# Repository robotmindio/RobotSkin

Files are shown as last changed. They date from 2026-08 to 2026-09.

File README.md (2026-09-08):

# RobotSkin

<p align="center">
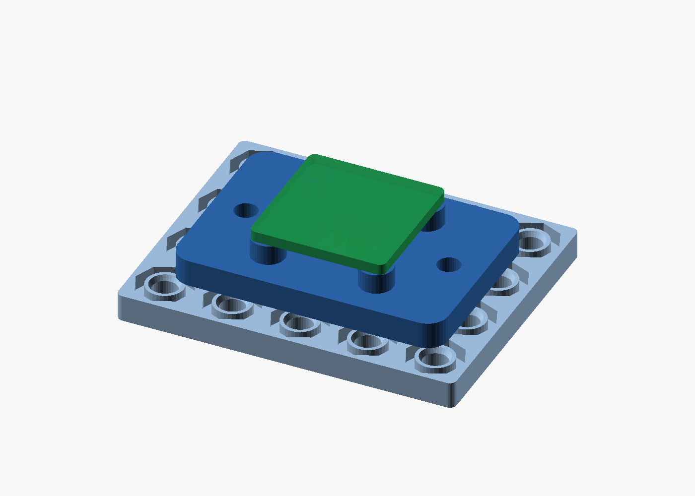
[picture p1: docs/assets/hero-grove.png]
A Grove sensor carrier locked to a RobotSkin plate
  
</p>

**Print a mechanical skin for your electronics.** RobotSkin turns sensors,
microcontrollers, cameras, and mounting surfaces into one reusable building
system. Print a plate, add a carrier or adapter, and lock the result with the
same 10 mm connector grid.

It is an OpenSCAD design library with ready-to-print STL exports—made for FDM
printers, prototypes that change, and projects that should not need a new
custom enclosure every time.

> **V0.1 is engineering hardware.** Print the calibration part before a larger
> build; the interface is reusable, but it is not yet load-rated.

## One interface, many jobs

- **Structural surfaces:** 8×8 plates and smaller full-through mounting plates.
- **Structures:** flat, inner-corner, and outer-corner joins.
- **Electronics:** Seeed Grove 2×2 Gesture, 4×2 IMU 9DOF, and 16×2 LCD
  carriers, a cable clip, a solid UNO-format carrier, and an inverted
  dual-USB-C 44-pin ESP32-S3 carrier with exposed pins.
- **Mounting adapters:** camera-tripod, 20-series extrusion, and TH35 DIN rail
  adapters, plus an H25T servo-horn plate.

<p align="center">
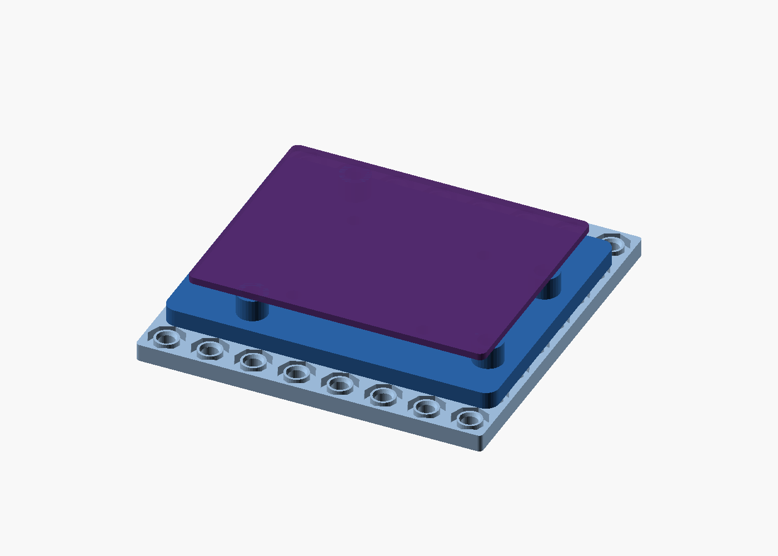
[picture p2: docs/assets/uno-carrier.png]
UNO-format carrier on a RobotSkin plate
  
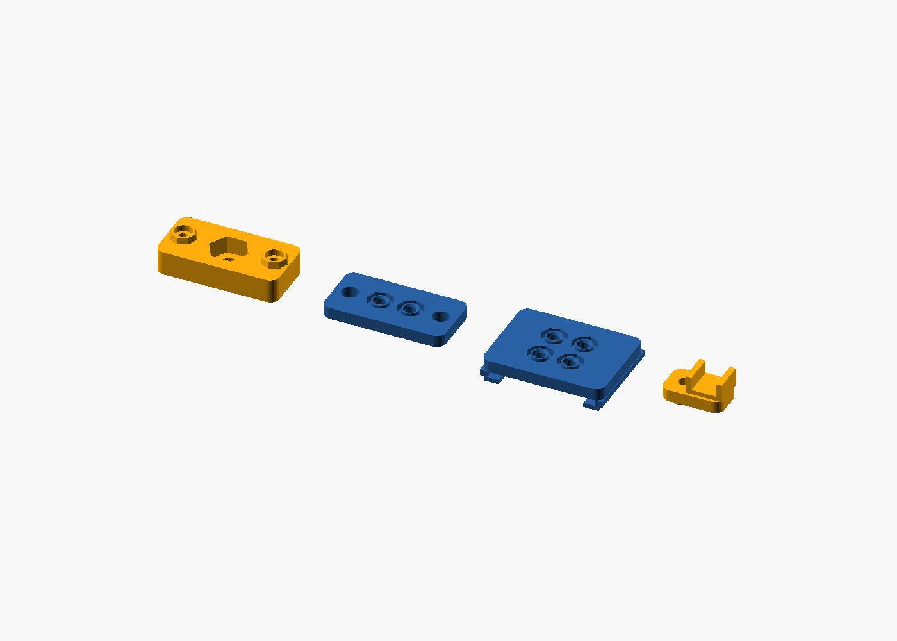
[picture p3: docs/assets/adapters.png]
RobotSkin mounting adapters
  
</p>

Every part shares the same connector: a blind octagonal port accepts a hollow
octagonal peg. Press it together for a temporary fit; for a permanent joint,
install an M3×3×4 heat-set insert in the plate port and fasten it through the
peg centre with an M3×6 pan-head screw.

That means a Grove LCD carrier, a DIN mount, and a tripod adapter all attach to the
same plate without inventing another mechanical standard.

## Start here

1. Print the calibration parts and tune your printer's fit.
2. Print a plate and a join or carrier.
3. Press-fit the peg into the plate port.
4. Add an insert and M3 screw only where you want the joint locked.

The exact calibration method is in [docs/CALIBRATION.md](docs/CALIBRATION.md).
Assembly instructions and the approved hardware are in
[docs/ASSEMBLY.md](docs/ASSEMBLY.md) and [docs/PRODUCT.md](docs/PRODUCT.md).

## Print a part

Download a released STL from `stl/`, or generate the complete set locally:

```bash
./scripts/build.sh
```

Run the fit samples first:

```bash
./scripts/build_test_parts.sh
```

Recommended orientation, materials, and acceptance checks are in
[docs/PRINTING.md](docs/PRINTING.md) and [docs/QUALITY.md](docs/QUALITY.md).

## Design your own part

The reusable public library is [scad/lib/robotskin.scad](scad/lib/robotskin.scad).
For example, define compatible plates by grid count:

```scad
include <scad/lib/robotskin.scad>

plate(8, 8);  // 80 × 80 mm
plate(5, 3);  // 50 × 30 mm
plate(3, 3, thickness=8);  // double-thickness custom plate
```

The public component API and mechanical rules are documented in
[docs/LIBRARY.md](docs/LIBRARY.md) and [docs/INTERFACE.md](docs/INTERFACE.md).
Export entry points live in `scad/parts/`; the build discovers them
automatically.

## Safety and release status

RobotSkin V0.1 is not load-rated or safety-critical hardware. Verify fit,
print quality, and your actual payload before use. The release package can be
regenerated and checked locally with:

```bash
./scripts/package_release.sh
```

This builds all STLs, validates that meshes are closed and connected, renders
previews, and writes a versioned archive plus SHA-256 checksum in `dist/`.

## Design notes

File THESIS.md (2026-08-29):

# RobotSkin thesis

RobotSkin is a modular system for sensors and robotics that children and
professionals can understand and use. It must stay as simple and coherent as
possible while allowing parts to connect by hand and be fixed with screws when
a permanent joint is needed. Water resistance is a later product goal, after
the shared dry mechanical interface passes its release gate.

## Minimum first part set

1. **8×8 plate** — the sole single-sided structural surface and mounting grid;
   two identical plates may be fastened back-to-back when both faces are needed.
2. **Flat join** — joins two plates edge-to-edge.
3. **90° join** — joins two plates at a right angle; an explicitly approved
   exterior variant uses the same port and peg interface.
4. **Grove sensor plaque** — mounts a Grove sensor on a plate.

Every future part must reuse this interface. Do not add a new connector,
carrier family, plate size, or enclosure until this four-part set has been
printed and validated.

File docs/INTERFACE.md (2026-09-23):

# RobotSkin interface

The production base plate is `plate(8,8)`: 80×80×4 mm with a full 8×8,
10 mm-pitch port grid. The library derives other plate dimensions from the
same grid standard. Every plate back is flat for reliable printing and surface
mounting.

| Feature | Dimension |
|---|---:|
| Annular octagonal port, across flats | 8.0 mm |
| Octagonal depth | 2.2 mm |
| Insert entry / pilot / insert | 4.6 mm × 0.8 mm / 3.7 mm × 3.0 mm / 4.0 mm OD M3×3×4 |
| Centre boss / peg clearance | 5.6 mm diameter / 5.9 mm diameter |
| Port backing wall | 1.0 mm |
| Corner mounting ports | Standard port plus 3.4 mm M3 clearance through backing wall |
| Through-plate ports | Standard port plus 3.4 mm M3 clearance through every backing wall |
| Peg root / tip | 8.3 / 7.7 mm across flats |
| Peg depth | 2.2 mm |
| Permanent lock | M3×6 pan-head screw, 2 mm insert engagement |
| Grove carrier retention | M2×6 / 1.7 mm pilot (2×2, 4×2); M2.5×6 / 2.1 mm pilot (LCD) |
| Profile 2020 mounting | Two M5 clearance holes, 30 mm apart |
| DIN rail | EN 60715 TH35 rigid end-slide channel |
| Tripod | Captive 1/4-20 hex nut, 4.5 mm maximum screw entry |
| UNO carrier | 68.58×53.34 mm outline, official asymmetric four-hole layout |
| ESP32-S3 dual-USB-C carrier | Header bodies: 22 mm inside, 28 mm outside, 2 mm high; pins outward; PCB body nominal 57×28 mm |

The circular central boss carries the insert for its full 3 mm depth. A visible 4.6 mm,
0.8 mm-deep entry cup leads into the 3.7 mm pilot, so the brass can start
straight from the exposed plate face before heat presses it into the interference fit. The peg
clears the boss, then its centre accepts an M3 screw. Its thinnest wall is 0.7 mm at the calibrated fit;
a four-peg field locates each join face and stops rotation. Every peg has an
identical through-hole and can accept a screw; four screws per tile are the
minimum recommended lock and all eight can be used for maximum strength.

Flat joins mount on the plate face across an edge seam. Angle joins mount in
the inside corner: one leg on the floor face and one on the wall face. Their
plate-contact faces are flat. Water resistance is outside the first release
until a sealed joint has been designed and tested.
Every join is one 20 mm tile spanning two adjacent port columns. A flat tile
has a 2×2 peg field on each plate. The inside angle is one continuous,
geometrically symmetric L-shaped part with the same 5/15 mm connector rows on
each face. Correctly seated plates touch along the full corner line; connector
fit must not be compensated by shifting either plate. Its outer ends use the
same rounded corners as the Grove carrier while both contact faces remain flat.
One to four tiles span a 20–80 mm run on a single surface.

`outer_angle_join` mounts below the floor and outside the wall. Its pegs use
the same port dimensions and sit 9 and 19 mm from the exterior corner.
Like the other joins, every peg has an identical screw-clearance hole.

The four corner stations remain standard connector ports. Their 3.7 mm insert
pilots end at the normal shoulder, while a 3.4 mm M3 clearance continues
through the final 1 mm backing wall. Each corner therefore accepts the normal
peg and heat-set insert or an M3 pan-head mounting screw through the plate.

One plate is the default product. `double_sided_plate(columns,rows)` provides
blind female ports on both faces, including the 40×10 mm 4×1 production row.
It is 8 mm thick so the opposing 3 mm insert pockets retain a 2 mm shared
backing wall. The two sides remain independent: do not drill its ports through.

`through_plate(columns,rows)` is the mounting-oriented variant: every grid
station remains a standard RobotSkin port while its M3 centre continues through
the full plate. The production exports are 5×3 (50×30 mm), 5×8 (50×80 mm),
8×8 (80×80 mm), and 12×10 (120×100 mm).

The Grove carriers have fixed, published PCB footprints: `grove_carrier_2x2()`
fits only the 20×20 mm Seeed Studio 101020083 Grove Gesture v1.0 with two
2.2 mm holes on its centre line; `grove_carrier_4x2()` fits only the 40×20 mm
Seeed Studio 101020585 Grove IMU 9DOF with its asymmetric three 2.2 mm holes.
The LCD carrier fits only Seeed Studio 104020111: its two RobotSkin lock
stations remain outside the 80×40 mm PCB footprint, while four bosses match
its 76×36 mm hole pitch. All Grove PCB pilots are blind and leave 2 mm of
plastic below the screw path.

`ld06_pj030_clamp_base()` and `ld06_pj030_clamp_bar()` retain the holeless
40×20×1.6 mm LD06 PJ030 controller. Two 40 mm bases mount facing inward on
plate rows 30 mm apart and use four total RobotSkin locks. Two bars use four
M3×6 screws and dedicated M3 inserts to clamp the long PCB edges with 0.1 mm
nominal preload. Both connector ends remain unobstructed.

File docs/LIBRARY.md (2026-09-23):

# RobotSkin OpenSCAD library

Include `scad/lib/robotskin.scad`. Dimensions passed to public part modules are
port counts unless a parameter explicitly says otherwise.

```text
standards
  -> port_cut / peg / heat_set_insert
    -> connector_grid / plate_body / join_panel / join_leg
      -> plate / joins / carriers / mounting adapters
        -> scad/parts entry point -> STL
```

## Finished parts

```scad
plate(columns, rows, thickness=RM_PLATE_T);
through_plate(columns, rows, thickness=RM_PLATE_T);
double_sided_plate(columns, rows, thickness=2*RM_PLATE_T);
h25t_horn_plate_3x3(thickness=2*RM_PLATE_T,
                     hub_radius=RM_STS3215_HUB_RADIUS);
h25t_port_cube_3x3();
flat_join(width_ports=2, depth_ports=2);
angle_join(width_ports=2, depth_ports=2);
outer_angle_join(width_ports=2, depth_ports=2, plate_t=RM_PLATE_T);
grove_carrier_2x2();
grove_carrier_4x2();
ld06_pj030_clamp_base();
ld06_pj030_clamp_bar();
grove_lcd_16x2_carrier();
tripod_adapter();
profile_2020_adapter();
din_rail_adapter();
grove_cable_clip();
uno_carrier();
rpi5_usb_carrier();
rpi5_table();
esp32_s3_devkitc_carrier();
pogo_pin_mount();
```

`plate()` requires integer dimensions of at least 2×2. Width and height are
derived as `count × RM_GRID`; `thickness` defaults to 4 mm and may be increased
for custom structural plates. The four corner ports receive the M3 through bore.
`through_plate()` uses the same dimensions and identical octagonal ports, but
continues the 3.4 mm M3 centre path through the backing wall at every station.
`double_sided_plate()` permits positive integer dimensions, including a 4×1
row, and provides standard blind female ports on both faces. It is 8 mm thick
by default, retaining a 2 mm wall between the opposing insert pockets; its
ports are blind, not M3-through.
Join counts control their connector field without changing the shared port,
peg, hardware, or fit standard.

`h25t_horn_plate_3x3()` is an 8 mm, 30×30 mm STS3215 drive plate. It reserves its
four cardinal stations for the STS3215/LeRobot H25T horn's 4×M3 pattern at
7 mm radius and keeps four corner RobotSkin ports with M3-through paths. The
centre screw and four surrounding horn screws all install from the port face;
the plate does not print a servo spline.

`h25t_port_cube_3x3()` mates to those four corner ports with lower pegs and
provides a 30×30×30 mm hub. Its centre and four top edge-centre stations are
female ports; the corners are 22 mm deep M3 head-access bores. Each vertical face
keeps its lower two centred ports and leaves its upper station flat to prevent
intersection. Four corner screw paths continue through the lower pegs into the
drive-plate inserts.

`grove_carrier_2x2()` fits the Seeed Studio 101020083 Grove Gesture v1.0:
its 20×20 mm PCB and two 2.2 mm holes on the centre line. `grove_carrier_4x2()`
fits the Seeed Studio 101020585 Grove IMU 9DOF (ICM20600 + AK09918): its
40×20 mm PCB and asymmetric three-hole pattern. Both retain their PCB with
top-installed M2 thread-forming screws; they do not imply fit for other Grove
modules with the same nominal outline.
The 4×2 carrier base is 40 mm long, matching the PCB; both RobotSkin locks
sit underneath it at ±15 mm rather than extending the carrier at either end.

`ld06_pj030_clamp_base()` is one of two 40 mm bases for the holeless
40×20×1.6 mm LD06 PJ030 controller. Each base has two RobotSkin locks and two
M3 insert pockets. Mount two copies facing inward on plate rows 30 mm apart.
Fasten two copies of `ld06_pj030_clamp_bar()` with four M3×6 screws to clamp
the PCB edges while leaving its underside and both connector ends open.

`grove_lcd_16x2_carrier()` fits only the Seeed Studio 104020111 Grove 16×2 LCD
(White on Blue): its 80×40 mm PCB and four 2.5 mm mounting holes at a 76×36 mm
pitch. The two RobotSkin M3 lock stations remain outside the PCB footprint;
four raised bosses accept top-installed M2.5 thread-forming screws.

`uno_carrier()` follows the official 68.58×53.34 mm UNO outline and asymmetric
four-hole pattern. Its main body is one continuous flat plate interrupted only
by screw paths. Four symmetric RobotSkin locks remain hidden below the board.

`rpi5_usb_carrier()` fits a Raspberry Pi 5 beside a Waveshare PCIe TO USB 3.2
Gen1 Board (C). The two PCBs sit on 5 mm standoffs above a compact 100×66 mm
carrier, with their long edges adjacent and mounting rows aligned; the
Waveshare USB ports face outward.
Eight RobotSkin locks attach the empty carrier before either PCB is installed.

`rpi5_table()` is an open-sided 120×100 mm protective top on four RobotSkin
legs. Its underside sits 30 mm above the plate, clearing the carrier-mounted
Raspberry Pi 5 with the official active cooler. Recessed access bores retain
the standard M3×6 lock screws at all four feet.

`esp32_s3_devkitc_carrier()` targets the user's dual-USB-C ESP32-S3 board.
Confirmed header dimensions are 22 mm inside, 28 mm outside and 2 mm high:
3 mm-wide strips on 25 mm centres. The 57 mm board-body length excludes the
projecting antenna; the 28 mm PCB envelope, 1.6 mm PCB thickness and 2.54 mm
pin pitch remain nominal assumptions, not additional caliper measurements.

The 60×32.6 mm carrier has a solid central deck, continuous side cheeks and
four consecutive RobotSkin locks. One-millimetre relief slots isolate the four
spring arms without leaving exposed towers. Both centre end openings remain
open for USB cables and the projecting antenna. Four outside
arms wrap around the PCB and catch the exposed header tops. Continuous edge
seats interrupted only at the spring arms, plus corner stops, locate the PCB without preloading the soldered rows.
`RM_ESP32_S3_DEVKITC_SNAP_OVERLAP` (0.2 mm) and `SNAP_GAP` (0.2 mm, same prefix)
control retention and vertical clearance. Increase overlap only after checking
jumper clearance: nominal 2.54 mm housings have only 0.03 mm lateral clearance
at the hooks. Physical fit, release force and durability are not yet verified.

`scad/source/esp32_fit.scad` preserves the board/connector envelope and assembly
preview. `python scripts/check_esp32_fit.py` checks unwanted intersections with
the PCB, headers, pins, solder, nominal jumpers, USB cable plugs and lock-screw
heads. It runs in the normal build; it is not a physical qualification test.

`pogo_pin_mount()` is a one-piece capsule face with a continuous rear rail and
six standard downward RobotSkin pegs at 10 mm pitch, perpendicular to the
contacts. Integral locating posts enter the connector's existing flange holes;
rear M2 screws and washers retain it without visible front fasteners. The rear
remains open. The module uses assembly orientation; its wrapper places the
peg tips on the bed, with support under the rail. Revision E joins the peg rail
directly to the rear rim, under the connector, with no spacer bridges or clamps.
See [product compatibility](PRODUCT.md) for the nominal drawing dimensions and
remaining fit measurements. `scad/source/pogo_fit.scad` shows the assembly
(`MODE="mounted"` adds a RobotSkin plate). `python scripts/check_pogo_fit.py`
checks the connector, mating flange, cables, empty-mount driver paths and
installed screw heads, then measures the mesh hole centres during the normal
build. It does not establish spring travel or physical screw retention.

The mounting adapters deliberately expose RobotSkin in the useful direction:
`tripod_adapter()` places two upward pegs under a plate, while the 2020-profile
and DIN-rail adapters provide female ports for carriers. The DIN part is a
rigid end-slide mount, not a material-dependent snap clip.

## Reusable components

```scad
connector_grid(columns, rows, direction="down", cut=false,
               body_t=RM_JOIN_T, fit=RM_PEG_FIT);
connector_peg(direction="down", fit=RM_PEG_FIT);
connector_screw_cut(direction="down", body_t=RM_JOIN_T);
plate_body(columns, rows);
plate_port_cuts(columns, rows);
plate_corner_through_cuts(columns, rows);
plate_all_through_cuts(columns, rows);
join_panel(width, min_row, max_row);
join_leg(width, length);
grove_pcb_standoff(position);
```

Directions are `down`, `forward`, `up`, and `backward`. Screw and port modules
are negative geometry: call them inside `difference()`.

## Interface primitives

```scad
port_cut(fit=RM_PORT_FIT, bore=undef);
peg(fit=RM_PEG_FIT);
heat_set_insert();
```

These define the physical compatibility boundary. Prefer the component and
finished-part modules unless a new product genuinely needs custom placement.

## Grid functions

```scad
grid_size(count);
grid_positions(count);
edge_rows(depth_ports);
flat_rows(depth_ports);
outer_rows(depth_ports, plate_t=RM_PLATE_T);
is_corner_index(column, row, columns, rows);
grid_station_outside(distance);
```

## Mechanical standard

`RM_GRID`, port dimensions, peg dimensions, insert geometry, plate thickness,
and screw clearances are shared system constants. Do not pass replacements into
individual parts: changing them locally would create incompatible products.

Only the calibrated manufacturing values are expected to vary between printer
and material profiles:

```scad
RM_PORT_FIT
RM_PEG_FIT
RM_INSERT_BORE
```

The repository exports one validated candidate per product family. Additional
sizes should be exported only after the first physical example of that family
passes its release gate.

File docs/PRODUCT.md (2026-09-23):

# RobotSkin V0.1 product definition

`VERSION` is the product-package version. Part geometry uses revision letters;
changing fit, interfaces, hole locations, or external dimensions requires a new
revision. Documentation or packaging-only corrections increment the package
version without changing the part revision.

V0.1 is engineering-evaluation hardware. It has no certified load rating and
is not a safety component. A production release requires every gate in
`QUALITY.md` to pass with recorded results.

## Production SKUs

| SKU | Export | Revision | Product |
|---|---|---|---|
| RM-PL-0402-A | `plate_4x2.stl` | A | 40×20 mm single-sided plate |
| RM-PL-0808-A | `plate_8x8.stl` | A | 80×80 mm single-sided plate |
| RM-PLD-0401-A | `double_sided_plate_4x1.stl` | A | 40×10×8 mm plate with four blind female ports on each face |
| RM-PT-0503-A | `through_plate_5x3.stl` | A | 50×30 mm plate, every port M3-through |
| RM-PT-0508-A | `through_plate_5x8.stl` | A | 50×80 mm plate, every port M3-through |
| RM-PT-0808-A | `through_plate_8x8.stl` | A | 80×80 mm plate, every port M3-through |
| RM-PT-1210-A | `through_plate_12x10.stl` | A | 120×100 mm plate, every port M3-through |
| RM-JF-0202-A | `flat_join.stl` | A | 2×2 + 2×2 coplanar join |
| RM-JI-0202-B | `angle_join.stl` | B | 2×2 + 2×2 inside 90° flush-butt join |
| RM-JO-0202-B | `outer_angle_join.stl` | B | 2×2 + 2×2 outside 90° flush-butt join |
| RM-GR-0202-A | `grove_carrier_2x2.stl` | A | Seeed Studio 101020083 Grove Gesture v1.0 carrier |
| RM-GR-0402-B | `grove_carrier_4x2.stl` | B | 40 mm-long Seeed Studio 101020585 Grove IMU 9DOF carrier |
| RM-LD-PJ03-C | `ld06_pj030_clip_carrier.stl`; `ld06_pj030_clamp_bar.stl` | C | Bolted edge clamp for LD06 PJ030 controller; print two of each |
| RM-GR-L162-A | `grove_lcd_16x2_carrier.stl` | A | Seeed Studio 104020111 Grove 16×2 LCD carrier |
| RM-TR-1420-A | `tripod_adapter.stl` | A | 1/4-20 tripod adapter |
| RM-PF-2020-A | `profile_2020_adapter.stl` | A | 20-series slot-6 adapter |
| RM-DN-TH35-A | `din_rail_adapter.stl` | A | TH35 end-slide adapter |
| RM-CC-GRV1-A | `grove_cable_clip.stl` | A | Grove cable clip |
| RM-PC-UNO3-C | `uno_carrier.stl` | C | Solid UNO R3-form-factor carrier |
| RM-PC-RPI5U-A | `rpi5_usb_carrier.stl` | A | Raspberry Pi 5 + Waveshare USB Board (C) carrier |
| RM-PC-RPI5T-A | `rpi5_table.stl` | A | Raspberry Pi 5 open protection table |
| RM-PC-ES3DC-F | `esp32_s3_devkitc_carrier.stl` | F | Solid-deck one-piece carrier for the 44-pin dual-USB-C ESP32-S3 board |
| RM-PG-2P-E | `pogo_pin_mount.stl` | E | Compact outward-facing pogo mount with six directly attached RobotSkin pegs; nominal fit candidate |
| RM-SV-H25T-D | `h25t_horn_plate_3x3.stl` | D | STS3215 H25T 7 mm-radius drive plate with horn-screw clearance |
| RM-SV-H25C-F | `h25t_port_cube_3x3.stl` | F | STS3215 drive plate to compact five-face RobotSkin end-effector hub |

## Authoritative hardware BOM

Quantities are per occupied attachment unless a part row says otherwise.
Vendor approval is still open; substitute hardware only when every listed
dimension and material requirement is met.

| Hardware ID | Approved engineering specification | Used by | Quantity |
|---|---|---|---:|
| HW-INS-M3-334 | Heat-set insert, M3 female, 3 mm long, 4.0 mm OD | RobotSkin port; UNO standoff; PJ030 clamp | 1 per lock or clamp screw |
| HW-SCR-M3X6-PH | M3×6 pan-head machine screw | Standard RobotSkin lock; PJ030 clamp | 1 per lock or clamp screw |
| HW-SCR-M3X4-PH | M3×4 pan-head machine screw | UNO PCB | 4 |
| HW-SCR-M3X8-PH | M3×8 pan-head machine screw | H25T horn plate | 4 |
| HW-SCR-M3X10-PH | M3×10 pan-head machine screw | H25T end-effector hub lock | 4 |
| HW-HUB-STS3215-H25T | Supplied STS3215 H25T horn, 4×M3 at 7 mm radius | H25T horn plate | 1 |
| HW-SCR-M2X3-TF | M2×3 thread-forming screw for plastic, measured 3 mm under head | Pogo connector flange | 2 |
| HW-WASHER-M2-503 | M2 flat washer, 5 mm OD, 2.2 mm ID, 0.3 mm thick | Pogo connector flange | 2 |
| HW-SCR-M2X6-TF | M2×6 thread-forming screw for plastic | Grove 2×2 or 4×2 PCB | 2 or 3 |
| HW-SCR-M25X6-TF | M2.5×6 thread-forming screw for plastic | Grove LCD PCB | 4 |
| HW-NUT-1420-HX | 1/4-20 hex nut, 11.3 mm maximum across flats, 5.8 mm maximum thick | Tripod adapter | 1 |
| HW-SCR-M5-PH | M5 screw sized for extrusion engagement | 2020 adapter | 2 |
| HW-NUT-M5-T20S6 | M5 T-nut for 20-series slot-6 extrusion | 2020 adapter | 2 |

Fastener finish is zinc-plated or stainless steel. Do not mix the M3×6 joint
screw with the shorter M3×4 UNO screw: the longer screw can bottom in the UNO
standoff insert after passing through a 1.6 mm PCB.

## Compatibility matrix

| Product | RobotSkin plate | Payload / external standard | Status and limit |
|---|---|---|---|
| Flat and angle joins | Any plate using the V0.1 10 mm port grid | — | Geometry verified; physical qualification pending |
| Grove 2×2 carrier | V0.1 ports | Seeed Studio 101020083 Grove Gesture v1.0, 20×20 mm PCB and two 2.2 mm holes | Geometry verified; physical fit pending; other 20×20 Grove boards require matching hole positions |
| Grove 4×2 carrier | V0.1 ports | Seeed Studio 101020585 Grove IMU 9DOF, 40×20 mm PCB and asymmetric three 2.2 mm holes | 40 mm-long base with locks beneath the PCB; geometry verified; physical fit pending; other 40×20 Grove boards require matching hole positions |
| LD06 PJ030 clamp carrier | Four V0.1 ports | 40×20×1.6 mm PJ030 controller without mounting holes | Two bases and two bolted bars clamp both long edges; four PCB-clamp screws and four plate locks; geometry verified, vibration qualification pending |
| Grove 16×2 LCD carrier | V0.1 ports | Seeed Studio 104020111, 80×40 mm PCB and 76×36 mm hole pitch | Geometry verified; physical fit pending |
| UNO carrier | V0.1 ports | Arduino UNO R3 mechanical outline and asymmetric holes | Mechanical pattern only; connector clearance must be checked per clone |
| Raspberry Pi 5 USB carrier | V0.1 ports | Raspberry Pi 5; Waveshare PCIe TO USB 3.2 Gen1 Board (C) | Mount the Waveshare PCB with USB ports facing outward; retain both PCBs with M2.5×6 thread-forming screws |
| Raspberry Pi 5 table | Four V0.1 ports | Raspberry Pi 5 USB carrier with official active cooler | 30 mm open-sided clearance; unrated protective top, not a safety component |
| ESP32-S3 dual-USB-C carrier | V0.1 ports | Measured headers: 22 mm inside, 28 mm outside, 2 mm high; 2×22 pins | Four continuous locks; outside hooks capture plastic above PCB; nominal PCB and connector envelopes; physical fit qualification pending |
| 2020 adapter | V0.1 pegs/carriers | 20-series, 6 mm slot, M5 T-nuts | Not for slot-5, slot-8, or 40-series profiles without verification |
| DIN adapter | V0.1 pegs/carriers | EN 60715 TH35 rail | Slides on from a free rail end; it is not a front-snap clip |
| Tripod adapter | V0.1 plate | 1/4-20 tripod screw | Maximum 4.5 mm screw entry into adapter |
| Cable clip | V0.1 plate | 7.5 mm nominal flat Grove cable | Verify cable jacket compression before repeated use |
| Two-contact pogo mount | Six consecutive V0.1 ports at 10 mm pitch | User-supplied two-contact connector screenshot | Nominal footprint below; pin travel, M2 retention and physical fit unverified |
| H25T drive plate | Four V0.1 corner female ports with M3-through paths | STS3215/LeRobot H25T horn, 4×M3 at 7 mm radius | All five horn screws install from the port face |
| H25T end-effector hub | H25T drive plate | Five top ports plus two ports on each vertical face | Four 22 mm corner M3 access bores lock into the drive plate |

Compatibility means nominal mechanical geometry only until the applicable
qualification record in `QUALITY.md` is complete.

## Two-contact pogo mount nominal footprint

Revision E targets the projecting-pin half shown in the user's drawing. The
screenshot suggests the following nominal connector dimensions; it is not a
substitute for a readable supplier drawing or measurements. Confirm especially
the contact diameter, mounting-hole bore and pin working height before printing.

| Feature | Candidate dimension |
|---|---|
| Connector flange | 55 × 15 × 3 mm, capsule outline |
| Existing flange mounting holes | 43 mm pitch, 4.5 mm bore |
| Pin centres / nominal pin diameter | 20 mm / 6 mm |
| Printed pin clearance holes | 6.4 mm diameter |
| Contact face | 60 × 18 × 0.8 mm, two apertures and a 0.3 mm perimeter bevel |
| Mount body, excluding RobotSkin pegs | 60 × 14.1 × 21 mm |
| Pin centre above RobotSkin mating surface | 12 mm |
| Nominal rear connector body used in clearance check | 31.3 mm wide × 11 mm high × 12 mm behind flange |
| Locating posts | 4.2 mm OD, 2.8 mm high, 1.7 mm blind screw pilots |
| Cable route tested behind body | 24 mm wide × 8 mm high, open rear exit |
| RobotSkin pegs | Six at 10 mm pitch, X = −25, −15, −5, 5, 15, 25 mm; row 9.1 mm behind face; axes perpendicular to contacts |

The flange pocket has 0.2 mm perimeter clearance. Two M2×3 thread-forming
screws with 0.3 mm-thick washers clamp the existing flange holes onto the
locating posts, with nominal 2.5 mm thread engagement and 1.1 mm of material
between the screw tip and front surface. The 0.9 mm pilot floor is blind.
Do not substitute longer screws: they can pierce the front. No printed clamps
or accessory heat-set inserts are needed. Six standard M3×6 screws and six
standard plate inserts populate all RobotSkin locks. Their 0.4 mm-deep head
seats give 2.4 mm insert engagement and 0.5 mm clearance between the nominal
2.4 mm-high heads and connector body. Use heads no taller than 2.4 mm.
Fasten these locks before fitting the connector; the installed body covers the central screwdriver paths.

The 0.8 mm skin consumes 0.8 mm of available pin projection. The mating half
must reach the supplier's working compression before touching the printed
face. The preview's 5 mm projection is illustrative; stroke and working
height remain unconfirmed. This mount does not fit the flush-contact half.
Check the M2 retention in the first PETG print; CAD clearance is not physical
qualification. Revision A's separate clamps are obsolete and must not be used
with later revisions.

### Drawing-to-model hole audit

Both diagrams show the same nominal contact and mounting centres. The upper
sheet depicts the flush-contact half; the lower sheet is the projecting-pin
half targeted here. The readable nominal callouts match the model as follows:

| Drawing feature | Printed interface | Review |
|---|---|---|
| 20 mm contact pitch | Two apertures at X = ±10 mm | Centres match |
| 43 mm flange mounting pitch | Posts and blind pilots at X = ±21.5 mm | Centres match |
| Ø4.5 flange mounting bore | Ø4.2 locating post, Ø1.7 pilot for the rear M2 screw | Intentional 0.3 mm diametral post clearance; not a Ø4.5 hole in the mount |
| Contact diameter and small tolerances | Ø6.4 aperture based on a nominal Ø6 contact | Callout insufficiently legible; not confirmed from this screenshot |

`check_pogo_fit.py` measures mesh sections to verify the above printed diameters
and centre locations plus all six RobotSkin pegs. That verifies CAD output,
not unreadable vendor dimensions. A full-height mating-flange sweep also
checks that the rail leaves 0.5 mm below the nominal mating flange.
The contact face points away from the RobotSkin plate. The 10 mm-deep rail
starts at the rear rim with no bridge gap. The connector sits above its
recessed screw heads; the connector's rear body and terminals project beyond
the rail, leaving the cable exit open. Driver access is checked before the
connector is installed, then installed head clearance and rear M2 access are
checked with the connector present. Remove the connector before accessing
covered RobotSkin lock screws.

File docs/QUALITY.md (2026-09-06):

# RobotSkin V0.1 acceptance and rating plan

V0.1-alpha is unrated engineering-evaluation hardware. Do not use it to support
people, safety equipment, suspended loads, or valuable equipment. Publishing a
working-load rating requires the tests below on production-equivalent material
and process; source geometry alone is not evidence of strength.

## Release acceptance

Record part revision, STL SHA-256, printer, profile, material lot, conditioning,
operator, date, sample count, measurements, failures, and disposition.

| Gate | Sample and method | Acceptance |
|---|---|---|
| Mesh | Every production STL, `scripts/validate_stl.py` | Watertight, consistent winding, positive volume, one connected shell |
| Grid | Alignment test compiled by `scripts/build.sh` | All OpenSCAD assertions pass |
| Visual | Every printed part | No cracks, missing walls, delamination, blocked holes, or loose material |
| Peg fit | 5 joints from the selected calibration | Seats fully by hand; no crack; no perceptible rotation under hand load |
| Repeatability | Same 5 joints | Ten install/remove cycles; all still seat and retain alignment |
| Insert installation | 10 inserts | Flush ±0.2 mm; no split or visible port distortion |
| Locked joint | 5 flat and 5 angle joints | M3×6 tightens without bottoming, stripping, or distortion |
| Plate flatness | 5 plates, flat reference surface | Maximum corner lift 1.0 mm before assembly |
| PCB carrier | 3 carriers with intended real PCB | All fasteners or clips engage; no board bending; connectors and antenna remain accessible |
| PJ030 vibration retention | 3 populated clamp assemblies, production-equivalent robot vibration profile | No PCB migration, loose screws or inserts, cracks, connector strain, or loss of controller function |
| Printability | Every SKU in release profile | Completes in documented orientation with only documented supports |

## Load qualification and published rating

Test at least five production-equivalent samples for each claimed load case:
flat-joint tension, flat-joint shear, angle-joint bending, plate surface mount,
DIN retention, 2020 retention, and tripod pull-out. Apply load gradually in a
guarded fixture, record first permanent deformation and ultimate failure, and
retain the raw results.

The published working load for a load case is the lower of:

1. one third of the lowest ultimate failure load; and
2. one half of the lowest load causing permanent deformation or loss of function.

Round the result down, state the material, print orientation, temperature, and
fastener configuration, and rerun the affected test whenever geometry,
material, print profile, insert, or screw specification changes. Until those
records exist, the authoritative load rating is **unrated / no load-bearing
claim**.

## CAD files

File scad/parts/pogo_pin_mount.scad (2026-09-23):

include <../lib/robotskin.scad>

// Peg tips on bed; support the rail underside and horizontal locating posts.
translate([0,0,RM_PORT_DEPTH-RM_EPS]) pogo_pin_mount();

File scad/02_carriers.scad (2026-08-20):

include <rm_common.scad>
PCB=[20,20];
W=PCB[0]+2*(1.7+0.5);
print_on_x_edge(W) sensor_carrier(PCB);

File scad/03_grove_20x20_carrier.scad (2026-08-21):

include <rm_common.scad>

module grove_20x20_carrier() {
  pcb=[20,20];
  clearance=0.35+RM_FIT;
  wall=1.6;
  wall_h=3;
  floor=RM_LINK_T;
  peg_d=1.9-2*RM_FIT;
  pocket=[pcb[0]+2*clearance,pcb[1]+2*clearance];
  outer=[pocket[0]+2*wall,pocket[1]+2*wall];
  assert(peg_d > 0, "RM_FIT makes the Grove pegs invalid");
  difference() {
    union() {
      translate([-outer[0]/2,-outer[1]/2,0])
        rounded_box([outer[0],outer[1],floor+wall_h],2);
      translate([-16,-5,0]) rounded_box([32,10,floor],3);
      for(x=[-RM_EDGE_MARGIN,RM_EDGE_MARGIN])
        translate([x,0,0]) rotate([180,0,0]) mount_peg();
    }
    translate([-pocket[0]/2,-pocket[1]/2,floor])
      rounded_box([pocket[0],pocket[1],wall_h+RM_EPS],1);
    translate([-6,outer[1]/2-wall-RM_EPS,floor])
      cube([12,2*wall+2*RM_EPS,wall_h+RM_EPS]);
    for(x=[-RM_EDGE_MARGIN,RM_EDGE_MARGIN])
      translate([x,0,floor]) rotate([180,0,0])
        optional_screw_cut(floor+RM_PORT_DEPTH);
  }
  for(x=[-8,8], y=[-8,8])
    translate([x,y,floor]) cylinder(h=1.2,d=peg_d);
}

// Side orientation keeps the tray and its two integral mounting pegs
// support-free on FDM printers.
translate([0,0,12]) rotate([90,0,0]) grove_20x20_carrier();

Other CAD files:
scad/09_cable_clip.scad
scad/00_fit_tests.scad
scad/parts/angle_join.scad
scad/parts/din_rail_adapter.scad
scad/parts/double_sided_plate_4x1.scad
scad/parts/esp32_s3_devkitc_carrier.scad
scad/parts/flat_join.scad
scad/parts/grove_cable_clip.scad
scad/parts/grove_carrier_2x2.scad
scad/parts/grove_carrier_40x40.scad
scad/parts/grove_carrier_40x60.scad
scad/parts/grove_carrier_4x2.scad
scad/parts/grove_lcd_16x2_carrier.scad
scad/parts/grove_plaque.scad
scad/parts/h25t_horn_plate_3x3.scad
scad/parts/h25t_port_cube_3x3.scad
scad/parts/ld06_pj030_clamp_bar.scad
scad/parts/ld06_pj030_clip_carrier.scad
scad/parts/lekiwi-lidar-base.scad
scad/parts/outer_angle_join.scad
scad/parts/plate_4x2.scad
scad/parts/plate_8x8.scad
scad/parts/profile_2020_adapter.scad
scad/parts/rpi5_table.scad
scad/parts/rpi5_usb_carrier.scad
scad/parts/through_plate_12x10.scad
scad/parts/through_plate_5x3.scad
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

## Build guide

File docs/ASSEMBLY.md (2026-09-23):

# RobotSkin assembly

Use the numbered sequence in
[`ASSEMBLY_DRAWINGS.svg`](ASSEMBLY_DRAWINGS.svg) as the visual assembly guide.

## Hardware

Each occupied lock station uses one M3×3×4, 4.0 mm-OD brass heat-set insert
and one M3×6 pan-head screw. The insert is heat-set flush into the 3 mm-deep,
blind centre bore of the plate's female port; it does not pass through the
plate. Its M3 threaded centre remains open for the screw. The join or Grove
carrier only supplies peg guidance and a screw-clearance path.

## Sequence

1. For a permanent joint, heat-set one insert at every lock station you will
   use, from the exposed plate face.
2. Press the pegs into the matching plate ports.
3. Drive one M3×6 screw through each occupied lock station into its insert.

Each join tile has eight identical lock stations: four on each attached plate.
For ordinary permanent assembly, use the four stations farthest from the seam
or corner. Use all eight when maximum strength is required.
Each Grove carrier has two M3 lock stations outside its PCB footprint. Fasten
the carrier first, then place the specified PCB on its standoffs and drive the
required thread-forming screws into the blind pilots from above: two M2 for
the 2×2 Gesture carrier, three M2 for the 4×2 IMU carrier, or four M2.5 for
the LCD.
The M3 locks remain accessible without removing the PCB. Press-fit-only
assembly remains removable.

The LD06 PJ030 clamp uses no PCB mounting holes. Print two clamp bases and two
clamp bars. Heat-set two M3×3×4 inserts into each base's exposed clamp pockets.
Mount the base peg rows 30 mm apart with the 1.2 mm ledges facing inward, then
lock all four pegs to the RobotSkin plate. Set the 40×20 mm controller on the
ledges and fasten each bar with two M3×6 screws. The short pads overlap only
1 mm of each PCB edge; confirm they touch bare PCB rather than a component.
Tighten evenly until the board cannot move, without bending it. For vibration
service, apply removable threadlocker only to the metal insert threads and
keep it off the printed plastic. Both short ends remain open for connectors.

The large rectangular opening between the LCD standoffs is only PCB and
connector clearance: leave it empty. Do not heat-set an insert in that opening
or in the LCD carrier. Except for the dedicated PJ030 clamp pockets and PCB
standoffs explicitly described above, brass M3 inserts belong in the matching
female ports of the RobotSkin plate.

## External mounting adapters

- `tripod_adapter`: place a standard 1/4-20 hex nut in the top pocket, then
  attach a RobotSkin plate over it using two M3×6 screws from the recessed
  underside stations. The plate traps the nut. Thread the tripod screw no more
  than 4.5 mm into the adapter.
- `profile_2020_adapter`: use two M5 screws through the exposed end holes into
  M5 T-nuts for 20-series slot-6 extrusion.
- `din_rail_adapter`: slide the rigid channel onto a TH35 rail from an exposed
  rail end. It is not a front-snap clip.
- `grove_cable_clip`: fasten or press its single peg first, then press the flat
  cable through the narrowed opening.
- `h25t_horn_plate_3x3`: place the plate on the STS3215 H25T horn, then install
  the supplied M3×6 centre screw and four M3×8 pan-head screws from the port
  face. The surrounding screws use the four holes at 7 mm radius.
- `h25t_port_cube_3x3`: heat-set inserts in the drive plate's four corner
  ports, press in the hub's four lower pegs, then lock them through the recessed
  top-corner M3 access bores. Remove these four screws to service the horn
  centre screw.

## UNO-format carrier

Install four standard M3×3×4 heat-set inserts into the standoff tops. Attach
the empty carrier to its four hidden plate ports first, then lower the
UNO-format board onto the
standoffs, and retain it with four M3×4 pan-head screws. Do not use M3×6 here:
after passing through a 1.6 mm PCB it can bottom beyond the 3 mm insert.
The exported UNO STL stands on its long frame edge for printing; its module in
the OpenSCAD library remains in assembly orientation.

## Raspberry Pi 5 USB carrier

Install the empty carrier at its eight hidden RobotSkin locks before mounting
either PCB. Place the Raspberry Pi 5 on the left standoffs and the Waveshare
PCIe TO USB 3.2 Gen1 Board (C) on the right standoffs, with its USB ports
facing the outer edge. The PCB long edges sit adjacent, as in the Waveshare
side-mounting layout, and their mounting rows align. Use eight M2.5×6
thread-forming screws (four per PCB), then route the supplied 16-pin PCIe cable
between the boards. Keep the top open for the Pi cooler and GPIO access.

## Raspberry Pi 5 protection table

Mount the populated Raspberry Pi carrier first. Align the table's four feet
with the surrounding RobotSkin ports, keeping every leg outside the carrier,
then press the table into place. For a locked installation, drive one M3×6
pan-head screw down each leg's access bore into the plate insert. Keep all four
open sides unobstructed so the active cooler can exhaust air.

## ESP32-S3 dual-USB-C carrier

Attach the empty carrier using its four consecutive RobotSkin lock stations
before fitting the board. Orient components toward the frame and both yellow
header strips and long pins away from it. Centre the PCB between the corner
stops; lower it evenly onto the side edge seats. The four outside hooks must
return over the outer edges of the yellow plastic, with no PCB bending.
The seats touch the PCB edge underneath; the hooks retain the plastic above it.

To remove it, gently move the two hooks on one side outward, lift that edge
slightly, then disengage the other side. Do not pull the pins or pry against
solder joints. Both central end openings remain free for the USB-C cables and
the projecting antenna. Test cable insertion/removal and ten latch cycles on
the first PETG print before using it on the robot. See [printing](PRINTING.md).

## Plate mounting

The four corner ports have an M3 clearance bore through the backing wall. Use
the same M3 pan-head screw type as the rest of the kit to mount one plate to a
threaded surface. For a double-sided assembly, place two identical plates
flat-back to flat-back and fasten the corner ports with suitably long M3
through-bolts or reusable binding posts. Do not glue the plate backs together.

## Two-contact pogo mount

Print one revision E mount. Confirm the
[nominal footprint and mating travel](PRODUCT.md#two-contact-pogo-mount-nominal-footprint)
against the actual connector. The older separate clamps are not used.

1. Install six standard M3 inserts in six consecutive RobotSkin ports, then
   attach the empty mount with six M3×6 screws in its recessed rear-rail seats.
   The contacts must face away from the RobotSkin plate. Tighten all six locks
   before fitting the connector: its body will cover the central driver paths.
2. Feed the contacts through the face from behind. Align the flange's two
   existing mounting holes over the locating posts and seat it in the capsule
   recess without forcing either the contacts or posts.
3. Place a 5 mm-OD, 0.3 mm-thick M2 washer over each rear flange hole. Fit one
   M2×3 thread-forming screw into each blind pilot, turning gently until the
   flange is retained. Do not use M2×6 screws here or overtighten the posts.
4. Route the leads directly out of the open rear, beyond the compact rail.
   Check pin movement and mate with the actual counterpart: its housing must not meet the skin before
   the pins reach their specified working compression. Verify cable bend and
   strain relief with the actual leads.

Both rear M2 screws remain accessible. To release the RobotSkin locks, first
remove the two M2 screws and lift the pogo connector off the locating posts.
Inspect post cracking, front-face distortion and retention during the first
physical fit check before repeated use.

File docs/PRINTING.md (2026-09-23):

# RobotSkin V0.1 FDM print profile

This is the release baseline, not a promise that every printer needs identical
settings. Calibrate `RM_PEG_FIT` and `RM_INSERT_BORE` before production.

| Setting | Baseline |
|---|---|
| Process | FDM/FFF |
| Material | PETG for functional evaluation; dry before printing |
| Nozzle / line width | 0.4 / 0.42 mm |
| Layer height | 0.20 mm |
| Walls | 4 |
| Top / bottom layers | 5 / 5 |
| Infill | 25% gyroid or cubic |
| Supports | Off except where listed below |
| Brim | Off; 5 mm for the UNO carrier if bed adhesion is marginal |
| Dimensional compensation | 0 initially; use calibration geometry, not slicer hole compensation, to tune the interface |

Do not scale STL files. Print one part at a time while qualifying a material or
printer. Orientations are already encoded in the production exports.

| Part family | Orientation / support |
|---|---|
| Plate and H25T horn plate | Flat back on bed; no support |
| Flat join and Grove carriers | Peg-side up; no support |
| LD06 PJ030 clamp | Bases as exported with clamp face on bed and pegs upward; bars flat; print two of each; no support |
| Inside/outside angle joins | As exported; local support below the horizontal connector row |
| UNO carrier | Long frame edge on bed; local support only beneath horizontal connector details when bridging fails |
| Raspberry Pi table | Tabletop on bed, legs and pegs upward; no support |
| ESP32-S3 dual-USB-C carrier | Long frame edge on bed; local supports beneath horizontal arms, side seats and pegs; inspect support removal access |
| Pogo mount | Peg tips on bed as exported; support beneath the rail and horizontal rear locating posts; keep supports out of peg bores and M2 pilots; the 0.8 mm face prints vertically |
| Tripod, 2020, DIN, cable clip | As exported; inspect slicer preview before first production run |

For the ESP32 carrier, use the PETG baseline and the exported side orientation.
Keep supports out of the 1 mm spring relief slots. Remove supports fully from
the hook ramps and seats without bending the arms.
The small 0.2 mm retaining overlap must survive slicing and printing; inspect
it before inserting the board. Check that jumper housings can seat at the four
hook positions. Do not force an oversized housing past a hook. Tune the header
fit in the source, not by scaling the STL. This revision needs physical fit and
cycle testing; passing the mesh/clearance checks does not qualify the print.

Reject a print when a port or peg has missing perimeters, an insert pocket is
closed, a wall is visibly delaminated, or the first layer changes a mating
feature. Record printer, nozzle, material brand, material lot, profile version,
and selected fit values with every qualification batch.

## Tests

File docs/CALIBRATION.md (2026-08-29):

# RobotSkin calibration

Build the dedicated tolerance kit with `./scripts/build_test_parts.sh`. It
writes only to `test-stl/`, not the production `stl/` directory.

The male set has five separate samples, left to right: `RM_PEG_FIT` 0.00,
+0.05, +0.10, +0.15, and +0.20 mm. Test them in any of the four nominal female
ports. Each sample has zero to four edge marks to identify its left-to-right
position. Select the loosest sample that remains firm and non-rotating, then
set `RM_PEG_FIT` to that value for production parts. The female tile also
checks the insert seat and M3×6 screw path.

Leave `RM_PORT_FIT` at 0.00 unless a separately printed female-port trial
shows it is required; it changes the socket and insert pilot together.

`tolerance_insert_set.stl` is independent of the peg-fit kit. Its five
plate-equivalent ports, left to right, use 3.75, 3.80, 3.85, 3.90, and 3.95 mm
insert pilots. Zero to four front-edge marks identify the bores. Heat-set one
of your actual inserts into each: select the largest bore that seats flush,
does not visibly distort the port, and resists a screw pull/twist test. Set
`RM_INSERT_BORE` to that bore only after this test.

| Date | Material | `RM_PEG_FIT` | Entry | Grip | Rotation | Verdict |
|---|---|---:|---|---|---|---|
| | | 0.00 | | | | |

## Connector release gate

After choosing both fits, print one flat join, one angle join, and only enough
plate geometry to exercise them. A connector design is ready for the first
release only when:

1. Every peg seats by hand without cracking or tools.
2. A press-fit assembly can be removed and reinstalled ten times without
   losing alignment.
3. Four M3×6 screws clamp a join without bottoming, splitting, or visible
   plate distortion.
4. A locked flat join resists hand twisting and a locked angle holds 90°.

Record failures here before changing geometry; do not add another connector
type to work around an uncalibrated shared interface.

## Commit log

2026-08-20 Simplify parametric OpenSCAD sources
    [01_universal_dock.scad, 02_carriers.scad, 03_apriltag_insert.scad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]
2026-08-20 Remove remaining speculative complexity
    [02_carriers.scad, 08_esp32_uno_mount.scad, 10_mount_adapters.scad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]
2026-08-20 Build modular gasketed cube beacon
    [04_beacon_flat.scad, 05_beacon_cube.scad, 08_esp32_uno_mount.scad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]
2026-08-20 Size cube beacon for Arduino UNO
    [05_beacon_cube.scad]
2026-08-20 Replace cube with modular hex dock panels
    [00_fit_tests.scad, 01_dock_panels.scad, 01_universal_dock.scad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]
2026-08-20 Orient parts for printing and split fit tests
    [00_fit_tests.scad, 02_carriers.scad, 04_beacon_flat.scad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]
2026-08-20 Replace snap hinges with direct hex panel joins
    [00_fit_tests.scad, rm_common.scad]
2026-08-20 Simplify carrier joint with optional M3 lock
    [00_fit_tests.scad, 04_beacon_flat.scad, 08_esp32_uno_mount.scad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]
2026-08-20 Add M3 insert pockets and clarify plate files
    [rm_common.scad]
2026-08-20 Simplify plate corners to tab and slot joints
    [00_fit_tests.scad, rm_common.scad]
2026-08-20 Establish coherent RobotMind V1 mechanical standard
    [00_fit_tests.scad, 01_dock_panels.scad, 01_plates.scad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]
2026-08-20 Deepen press fits and add corner M3 inserts
    [00_fit_tests.scad, rm_common.scad]
2026-08-20 Refactor SCAD libraries by interface ownership
    [02_grove_carriers.scad, 03_apriltag_insert.scad, 04_apriltag_beacon_carrier.scad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]
2026-08-21 Replace plate A/B edges with universal joint
    [00_fit_tests.scad, rm_common.scad]
2026-08-21 Refine universal plate edge proportions
    [rm_common.scad]
2026-08-21 Redesign plates for print and injection
    [00_fit_tests.scad, 09_injection_plate.scad, rm_common.scad]
2026-08-21 Simplify RobotMind around an 8 mm grid
    [00_fit_tests.scad, 01_plates.scad, 02_connectors.scad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]
2026-08-21 Add OpenSCAD assembly previews
    [03_grove_20x20_carrier.scad, 04_assembly_previews.scad]
2026-08-21 Build V4 solid double-sided panel system
    [00_fit_tests.scad, 01_panels.scad, 01_plates.scad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]
2026-08-21 Calibrate nominal peg from large coupon
    [rm_common.scad]
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2026-08-21 Revert "Add hexagonal panel variant"
    This reverts commit 2fd3b7476263651fd3ded5cee2e283e0886e3b97.
    [05_hex_panels.scad, rm_common.scad]
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2026-08-24 Restructure SCAD tree; align docs with battlement system
    [02_connectors.scad, 04_assembly_previews.scad, 05_edge_coupons.scad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]
2026-08-24 Fix battlement sockets as cuts; add seam and corner probes
    [corner_coupon.scad, edge_coupons.scad, rm_common.scad]
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2026-08-24 Add insert-coupled link system with grid alignment gate
    Replace battlement edges with clean butt seams joined by flat and angle
    link brackets. Ports now carry a concentric 3 mm bore seating an M3
    brass heat-set insert; every link hole is verified on a port centre by
    a build-gated assertion. Fix link columns for 80 mm links, restore the
    centre membrane against opposing bores, unify link hole drilling, and
    align all docs with the coupling system.
    [corner_coupon.scad, edge_coupons.scad, fit_tests.scad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]
2026-08-24 Specify M3x3x4 insert and document seat choice
    Select the 3 mm body brass heat-set insert (4.0 mm OD) so the blind
    bore seats it flush within the 8 mm panel; encode the part number in
    source.
    [rm_common.scad]
2026-08-24 Add seam coupon for bolted coupling validation
    The fit coupons exercised only peg and bore geometry; the bolted seam
    path had no physical test piece. Add a single slab whose four bores
    are grid-matched to the flat_link_40 holes, and wire it into the build
    so M3x3x4 inserts and screws can be validated on one small print.
    [seam_coupon.scad]
2026-08-24 Make test coupons carry through-bores for the metal insert
    The port and seam coupons now cut a full-depth 3.4 mm bore so the
    M3x3x4 brass insert seats and can be pushed out for reuse. This makes
    the insert seat unmistakable in the printed part and validates the
    coupling without full panels.
    [fit_tests.scad, seam_coupon.scad]
2026-08-24 Give fit coupons square grips and through bores
    The peg coupons now reuse the real integral peg construction on a
    square 12 mm rounded grip, with the centre bore extended through the
    grip so an M3 screw passes the whole coupon. The port coupon matches
    on a square grip.
    [fit_tests.scad]
2026-08-24 Make fit coupons minimal 1x1 square system tiles
    Both the port and peg coupons are now flat 40x40 square tiles built
    from the real constructive primitives: the port tile carries one
    blind_port_cut with its insert seat, the peg tile carries the real
    mount_peg proud of the face with a full-depth through bore. Removes
    the off-system 12 mm puck and keeps the coupling 1:1 with production.
    [fit_tests.scad]
2026-08-24 Engrave P/S/N/L letters on fit coupon tiles
    Adds a struck letter to each 20 mm square coupon so the four
    fit parts are identifiable by eye: P on the port tile, S/N/L on the
    peg tiles matching small/nominal/large delta.
    [fit_tests.scad]
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2026-08-25 Add connector tolerance calibration kit
    [alignment.scad, rm_system.scad, tolerance_female_2x2.scad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]
2026-08-25 Restore continuous join panels and add vocabulary sheet
    [rm_system.scad]
2026-08-25 Tighten join panel edges
    [rm_system.scad]
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2026-08-25 Strengthen and verify connector interface
    [alignment.scad, previews.scad, rm_system.scad]
2026-08-25 Shift fit coupon toward looser pegs
    [alignment.scad, rm_system.scad]
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2026-08-25 Use loosest calibrated peg fit
    [rm_system.scad]
2026-08-25 Replace long joins with two-column tiles
    [alignment.scad, rm_system.scad]
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2026-08-26 Replace double-sided plate with mountable base
    [alignment.scad, previews.scad, rm_system.scad]
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2026-08-26 Replace Grove plaque with serviceable carrier
    [alignment.scad, grove_carrier_20x20.scad, previews.scad]
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2026-08-27 Redesign UNO carrier as orthogonal frame
2026-08-27 Replace UNO frame with solid carrier plate
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2026-08-29 Add H25T horn plate and custom plate thickness
    [alignment.scad, h25t_horn_plate_3x3.scad]
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2026-08-29 Flip H25T center screw recess
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2026-09-04 Correct Waveshare USB board footprint
    [alignment.scad]
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2026-09-05 Replace generic Grove carriers with LCD carrier
    [alignment.scad, grove_carrier_20x20.scad, grove_carrier_20x40.scad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]
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2026-09-06 Replace PJ030 frame with printable rails
    [alignment.scad, ld06_pj030_clip_carrier.scad]
2026-09-06 Replace PJ030 pressure rails with bolted clamps
    [alignment.scad, ld06_pj030_clamp_bar.scad, ld06_pj030_clip_carrier.scad]
2026-09-07 Add inverted ESP32-DevKitC carrier
    [alignment.scad, esp32_devkitc_carrier.scad]
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2026-09-08 Replace ESP32 carrier with S3 slide mount
    [alignment.scad, esp32_devkitc_carrier.scad, esp32_s3_devkitc_carrier.scad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]
2026-09-08 Snap ESP32-S3 carrier onto pin headers
    [alignment.scad, esp32_s3_devkitc_end_cap.scad]
2026-09-08 Redesign ESP32 carrier for measured dual USB board
    [alignment.scad]
2026-09-08 Capture measured ESP32 headers with outside release hooks
    [alignment.scad, esp32_fit.scad]
2026-09-08 Unify ESP32 carrier sides and reinforce central deck
2026-09-10 Add thin-face pogo pin mount with rear flange clamps
    [alignment.scad, pogo_fit.scad, pogo_pin_clamp.scad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]
2026-09-10 Redesign pogo mount as compact capsule with concealed flange screws
    [alignment.scad, pogo_fit.scad, pogo_pin_clamp.scad]
2026-09-10 Move six pogo mount locks to a continuous outside row
    [alignment.scad, pogo_fit.scad, pogo_pin_mount.scad]
2026-09-10 Correct pogo orientation with peg rail behind connector
    [alignment.scad, pogo_fit.scad]
2026-09-10 Remove pogo mount bridges and tuck peg rail under connector
    [alignment.scad, pogo_fit.scad]
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2026-09-23 Add 4x2 single-sided plate
    Commits the untracked plate_4x2.scad (uses the existing plate()
    module, same as plate_8x8) and catalogs it in docs/PRODUCT.md as
    RM-PL-0402-A, following the plate_8x8/double_sided_plate_4x1 entry
    format. No library or interface changes: plate(columns,rows) already
    supports arbitrary positive integer dimensions.
    Verified: openscad --export-format csg alignment check passes; built
    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
    [plate_4x2.scad]
2026-09-23 Validate test-stl/*.stl in package_release.sh too
    package_release.sh bundles test-stl/ (calibration parts from
    build_test_parts.sh) into the release archive without ever validating
    those meshes. Run validate_stl.py against them as well.
    tolerance_male_set() intentionally places several independent test
    pegs side by side on one plate (not a single connected part), so the
    existing "exactly one shell" rule doesn't apply to it the way it does
    to production parts. Added --allow-multiple-shells to validate_stl.py
    (watertightness, winding, and volume are still checked in aggregate;
    only the single-shell requirement is skipped) and used it for the
    test-stl pass.
    Verified: full ./scripts/package_re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
